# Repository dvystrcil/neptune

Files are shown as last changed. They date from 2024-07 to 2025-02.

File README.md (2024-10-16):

# Whats new?

I have moved all my pre OpenNept4une work into the archive folder. This includes all my notes for using the BTT Eddy on the Elegoo firmware.

I will be storing my current configs here soon, but keep in mind that they work with Open Nept4une and my not be advisable for stock Elegoo firware.

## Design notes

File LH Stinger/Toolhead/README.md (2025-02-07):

Start...

## What to expect
- @15g lighter
- Uses LH Stinger proven concepts
-- Compatible with Voron hotends (four bolt)
-- LDO Orbiter v2.x compatible
- Lose of 

## BOM
- LDO Oriter v2.x
- [TZ V6 2.0](https://www.aliexpress.us/item/3256808120176947.html)
- 5015 24v fans - Dual bearing, not hydrolic 
- 4010 24v fan
- [Elegoo Breakout Board](https://www.aliexpress.us/item/3256806050452317.html) (optional)

Print with PETG, ASA, or ABS 

Notes:
- The LDO and Elegoo breakout board wiring match one for one. The upper two are paired to one coil and the lower two are paired to the other coil.
- BTT Eddy loctions. Some loss of X on the screw-tilt, I may need to find a better location for the Eddy.

## What needs to be completed
- [ ] Input Shaping
- [ ] Filament Calibration
- [ ] Set new screw tilt locations
- [ ] Save everything
- [ ] Tidy up left side wire harness
- [ ] Reprint purge bucket with 9mm less height
- [ ] Investigate how to add a filament cutter
- [ ] Perhaps reprint in ASA
- [ ] Add some before and after info

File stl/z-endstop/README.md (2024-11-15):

STL files for makeing the z-endstop for use with the Elegoo Neptune 4/4 Pro (not Plus or Max)

License:
[CC BY-NC 4.0](https://creativecommons.org/licenses/by-nc/4.0/)

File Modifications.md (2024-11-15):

# My Modifications

A list of all the modifications I have done to my Neptune 4 Pro

| Type | Paid | Works? | Notes |
| :--- | ----: | :----: | :---- |
| [Silicone Bushings](https://www.amazon.com/gp/product/B09NNFQQ8T/ref=ppx_yo_dt_b_search_asin_title?ie=UTF8&psc=1) | $7.99 | Y | Springs were not holding position. |
| [Oldham Couplings (x2)](https://www.amazon.com/gp/product/B0BZ56F15T/ref=ppx_yo_dt_b_asin_title_o00_s00?ie=UTF8&th=1) | $8.99 | Y | Noticeable improvement in Z banding. |
| [Shroud](https://www.printables.com/model/812526-neptune-4-plus-max-3x-5015-fan-printhead-threaded) | $$ | Y | I could ditch the blower and have improved airflow on the nozzle (where the work happens). I will provide a price later) |
| [EMMC 32Gb](https://www.amazon.com/dp/B0D1K3TNQN?ref=ppx_yo2ov_dt_b_fed_asin_title) | $21.00 | Y | Used it for upgrading and storage space. |
| [Thrust Bearings](https://www.amazon.com/dp/B07QKKWM2R?ref=ppx_yo2ov_dt_b_fed_asin_title) | $7.54 | Y | I am using these to improve the life of my steppers |
| [KUSBA](https://www.amazon.com/gp/product/B0C734JL4Z/ref=ppx_yo_dt_b_search_asin_title?ie=UTF8&psc=1) | $15.69 | Y | Improved printing, less ghosting. |
| [BTT Eddy](https://biqu.equipment/products/bigtreetech-eddy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) | $24.98 | Y | Beautiful first layers. [Adapter](https://www.printables.com/model/928061-neptune-4-btt-eddy-adapter) |
| [Bimetal Nozzle](https://www.amazon.com/dp/B0CKYXZCYC?ref=ppx_yo2ov_dt_b_fed_asin_title) | $9.97 | M | Might be leaving some scaring. It does hold its heat well and I can print PETG-CF without issue. |
| [USB Hub](https://www.amazon.com/dp/B07L32B9C2?ref=ppx_yo2ov_dt_b_fed_asin_title&th=1) | $9.99 | Y | Needed for expansion. |
| [Elegoo Harden Steel Nozzel](https://www.amazon.com/dp/B0CY3T6FHC?ref=ppx_yo2ov_dt_b_fed_asin_title&th=1) | $9.99 | N | Doesn't hold the heat well. The Bimetal is performing better. |
| [Creality A/B Plate](https://www.amazon.com/dp/B0C4NDBY8Z) | $19.99 | Y | Love it. |
| [z endstop](https://github.com/dvystrcil/neptune/blob/main/Z%20End%20Stop%20Modification.md) | $$ | Y! | Absolutely love it. |
| Axis Locks | 
| Cable Chains |
| Filament Feeder |
| Camera |

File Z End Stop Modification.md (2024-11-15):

Notes on how I added a Z endstop to my Neptune 4 Pro. This should be compatible with the non-pro, however, due to the nonexistent off-bed range of the X axis on the Plus and Max a different solution will need to be designed.

## License
[CC BY-NC 4.0](https://creativecommons.org/licenses/by-nc/4.0/)

## Limitations
- If the nozzle is dirty, your offset is not going to be accurate
- It may be difficult to clean the nozzle without homing first
- you cannot use bed corners on the same side as the offset end stop

## Parts
- [Cable Endstop Mechanical Limit Optical Switch Connection Wire](https://www.amazon.com/gp/product/B0B6FHZLLF) Note: 1M is too long, if you can find even a third of that length it would work.
- [X/Y/Z Axis End Stop Limit Switch](https://www.amazon.com/gp/product/B098PXX6Q7)
- [2.6x16mm Dowel Pins](https://www.amazon.com/gp/product/B0BCFN4RHN0)
- [0406 Sleeve Bearings](https://www.amazon.com/gp/product/B0CXXGHT1P)
- 2 - M3*6 button head screws
- 1 - M4*20 hex head bolt with nut (poor man's t-nut)
- [Printable Parts](https://github.com/dvystrcil/neptune/tree/main/stl/z-endstop)

## Code
When reading this configs keep in mind that the Pro has a bed size of 235x235 so the center would be 117.5,117.5
```
[stepper_z]
...
endstop_pin: ^!PC3
homing_speed: 8
homing_retract_dist: 5
second_homing_speed: 3
```
```
[gcode_macro Z_ENDSTOP_CALIBRATE]
rename_existing: Z_ENDSTOP_CALIBRATE_RAW
gcode: 
  BED_MESH_CLEAR
  G28
  G90 # Abs positioning
  G1 X117.5 Y117.5 F6000  
  Z_ENDSTOP_CALIBRATE_RAW {rawparams}
```
```
[safe_z_home]
...
home_xy_position: -5,117.5
```
```
[bed_mesh]
...
zero_reference_position: 117.5,117.5
```

## Installation Pictures
The -Z pin PC3
PXL_20241104_004744595 MP
I had to remove the top and both of the bottom panels to route the wire through, but there is plenty of clearance.

There is a clearance issue that needs to be resolved. In my case, there is no pressure from the arm so the rubbing is minimal.


## On and Off the Plate
- 0.2 layer height
- Any filament is OK
- Brim Type: Mouse ear
- I used supports: Normal with Snug




## References
- https://www.youtube.com/watch?v=Q2uBK5XzX4I Note: this video fails to mention what the zero_reference_position does.
- https://www.klipper3d.org/G-Codes.html?h=z_offset_app#z_endstop_calibrate
- https://www.klipper3d.org/G-Codes.html?h=z_offset_app#z_offset_apply_endstop
- https://www.klipper3d.org/Endstop_Phase.html
- https://www.klipper3d.org/Bed_Mesh.html?h=zero_reference_position#configuring-the-zero-reference-position

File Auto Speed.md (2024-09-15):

# Testing Auto Speed 

## Where to find it:
https://github.com/Anonoei/klipper_auto_speed

## Some explanation on how to use it:
https://www.youtube.com/watch?v=8d49_QUmP9k

## Running AUTO_SPEED with Autotune set to `silent`

```
// AUTO SPEED found maximum acceleration after 114.36s
// | X max: 8089
// | Y max: 12601
// 
// Recommended values:
// | X max: 6471
// | Y max: 10081
```
```
// AUTO SPEED found maximum velocity after 134.67s
// | X max: 92
// | Y max: 352
// 
// Recommended values
// | X max: 74
// | Y max: 282
// Recommended velocity: 74
```
```
// AUTO SPEED found recommended acceleration and velocity after 249.04s
// | X max: a6471 v74
// | Y max: a10081 v282
// Recommended accel: 6471
// Recommended velocity: 74
```

AUTO_SPEED_GRAPH_2024-09-14_22_30_47_x

AUTO_SPEED_GRAPH_2024-09-14_22_34_53_y

## Running AUTO_SPEED with Autotune set to `performance`

```
// AUTO SPEED found maximum acceleration after 76.15s
// | X max: 97937
// | Y max: 97937
// 
// Recommended values:
// | X max: 78350
// | Y max: 78350
```
```
// AUTO SPEED found maximum velocity after 97.30s
// | X max: 1261
// | Y max: 965
// 
// Recommended values
// | X max: 1009
// | Y max: 772
// Recommended velocity: 772
```
```
// AUTO SPEED found recommended acceleration and velocity after 173.47s
// | X max: a78350 v1009
// | Y max: a78350 v772
// Recommended accel: 78350
// Recommended velocity: 772
```




## Running with Autotune set to `performance` and some different defaults

After talking with SilencedFrost he said the accel wasn't making sense. My numbers were the same as the video, which was odd. I did some poking around and found this issue https://github.com/Anonoei/klipper_auto_speed/issues/25

So I used the same numbers as the person in the issue:
```config
[auto_speed]
margin: 2.5 ; How far away from your axes to perform movements
accel_min: 1000.0 ; Minimum acceleration test may try
accel_max: 30000.0 ; Maximum acceleration test may try

velocity_min: 50.0 ; Minimum velocity test may try
velocity_max: 700.0 ; Maximum velocity test may try
```

```
// AUTO SPEED found maximum acceleration after 76.51s
// | X max: 29395
// | Y max: 29395
// 
// Recommended values:
// | X max: 23516
// | Y max: 23516
```
```
// AUTO SPEED found maximum velocity after 77.16s
// | X max: 686
// | Y max: 604
// 
// Recommended values
// | X max: 549
// | Y max: 483
// Recommended velocity: 483
```
```
// AUTO SPEED found recommended acceleration and velocity after 153.68s
// | X max: a23516 v549
// | Y max: a23516 v483
// Recommended accel: 23516
// Recommended velocity: 483
```

The numbers still sound a little suspicious. Shouldn't the velocity be hitting 700, since the uncapped run was at 772?

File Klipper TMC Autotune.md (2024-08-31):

# Klipper TMC Autotune Notes

Notes on my experimentation with getting the Klipper autotune working on my Elegoo Neptune 4 Pro

## Installation

Read and install: https://github.com/andrewmcgr/klipper_tmc_autotune

## Configuration

Based on what SilentedFrost has discovered these are some of the attributes of the steppers. I can confirm that I am using the BJ42D22-53V04 for the X, assuming the Y will be identical. I will have to find evidence for the others.



Specs on the steppers: https://www.3djake.com/elegoo/stepper-motor-4

```ini
########################################
# Klipper TMC Autotune configuration
########################################

[motor_constants bj42d22-53v04]             ; 1.2A version of the stepper motor
resistance: 2.1
inductance: 0.0046
holding_torque: 0.4
max_current: 1.20
steps_per_revolution: 200

[ autotune_tmc stepper_x]
motor: bj42d22-53v04
tuning_goal: auto

[ autotune_tmc stepper_y]
motor: bj42d22-53v04
tuning_goal: auto
```

## Fixing Packages

### Enum error
https://github.com/andrewmcgr/klipper_tmc_autotune/issues/40

run:
```bash
source ~/klippy-env/bin/activate
pip install enum
deactivate
```

### Signature error

run:
```bash
source ~/klippy-env/bin/activate
pip install funcsigs
deactivate
```

Change this line:
https://github.com/andrewmcgr/klipper_tmc_autotune/blob/main/| autotune_tmc.py#L3
```python
import math, logging, os
from enum import Enum
from inspect import signature
from . import tmc
```
to
```python
import math, logging, os
from enum import Enum
#from inspect import signature
from funcsigs import signature
from . import tmc
```
Probably a better way to do this so it can try the first and fall back on the second

## Performance

Since I only have the XY steppers tuning I will do an X offset print and compare times and the sound.

| Auto | Silent | Performance |
| :--- | :----- | :--- |
| 5m25s | 5m24s | 5m24s |
| autotune_tmc set stepper_x pwm_freq=2 | autotune_tmc set stepper_x pwm_freq=2 | autotune_tmc set stepper_x pwm_freq=2 |
| autotune_tmc stepper_x ncycles=219 pfdcycles=73 | autotune_tmc stepper_x ncycles=219 pfdcycles=73 | autotune_tmc stepper_x ncycles=219 pfdcycles=73 |
| autotune_tmc set stepper_x tbl=1 | autotune_tmc set stepper_x tbl=1 | autotune_tmc set stepper_x tbl=1 |
| autotune_tmc set stepper_x toff=1 | autotune_tmc set stepper_x toff=1 | autotune_tmc set stepper_x toff=1 | 
| autotune_tmc seting hysteresis based on 24.0 V | autotune_tmc seting hysteresis based on 24.0 V | autotune_tmc seting hysteresis based on 24.0 V |
| dcoilblank = 0.010435, dcoilsd = 0.003278 | dcoilblank = 0.010435, dcoilsd = 0.003278 | dcoilblank = 0.010435, dcoilsd = 0.003278 |
| hysteresis = 0, htotal = 0, hstrt = 1, hend = -1 | hysteresis = 0, htotal = 0, hstrt = 1, hend = -1 | hysteresis = 0, htotal = 0, hstrt = 1, hend = -1 |
| autotune_tmc set stepper_x hstrt=0 | autotune_tmc set stepper_x hstrt=0 | autotune_tmc set stepper_x hstrt=0 |
| autotune_tmc set stepper_x hend=2 | autotune_tmc set stepper_x hend=2 | autotune_tmc set stepper_x hend=2 |
| autotune_tmc set stepper_x sgthrs=40 | autotune_tmc set stepper_x sgthrs=40 | autotune_tmc set stepper_x sgthrs=40 |
| autotune_tmc using max PWM speed 176.661987 | autotune_tmc using max PWM speed 176.661987 | autotune_tmc using max PWM speed 176.661987 |
| autotune_tmc set stepper_x pwm_autoscale=True | autotune_tmc set stepper_x pwm_autoscale=True | autotune_tmc set stepper_x pwm_autoscale=True |
| autotune_tmc set stepper_x pwm_autograd=True | autotune_tmc set stepper_x pwm_autograd=True | autotune_tmc set stepper_x pwm_autograd=True |
| autotune_tmc set stepper_x pwm_grad=15 | autotune_tmc set stepper_x pwm_grad=15 | autotune_tmc set stepper_x pwm_grad=15 |
| autotune_tmc set stepper_x pwm_ofs=33 | autotune_tmc set stepper_x pwm_ofs=33 | autotune_tmc set stepper_x pwm_ofs=33 |
| autotune_tmc set stepper_x pwm_reg=15 | autotune_tmc set stepper_x pwm_reg=15 | autotune_tmc set stepper_x pwm_reg=15 |
| autotune_tmc set stepper_x pwm_lim=4 | autotune_tmc set stepper_x pwm_lim=4 | autotune_tmc set stepper_x pwm_lim=4 |
| autotune_tmc set stepper_x tpwmthrs=1048575 | autotune_tmc set stepper_x tpwmthrs=0 | autotune_tmc set stepper_x tpwmthrs=1048575 |
| autotune_tmc set stepper_x en_spreadcycle=True | autotune_tmc set stepper_x en_spreadcycle=False | autotune_tmc set stepper_x en_spreadcycle=True |
| autotune_tmc set stepper_x tcoolthrs=391(24.0) | autotune_tmc set stepper_x tcoolthrs=391(24.0) | autotune_tmc set stepper_x tcoolthrs=391(24.0) |
| autotune_tmc set stepper_x semin=2 | autotune_tmc set stepper_x semin=2 | autotune_tmc set stepper_x semin=2 |
| autotune_tmc set stepper_x semax=4 | autotune_tmc set stepper_x semax=4 | autotune_tmc set stepper_x semax=4 |
| autotune_tmc set stepper_x seup=3 | autotune_tmc set stepper_x seup=3 | autotune_tmc set stepper_x seup=3 |
| autotune_tmc set stepper_x sedn=2 | autotune_tmc set stepper_x sedn=2 | autotune_tmc set stepper_x sedn=2 |
| autotune_tmc set stepper_x seimin=1 | autotune_tmc set stepper_x seimin=1 | autotune_tmc set stepper_x seimin=1 |
| autotune_tmc set stepper_x iholddelay=12 | autotune_tmc set stepper_x iholddelay=12 | autotune_tmc set stepper_x iholddelay=12 |
| autotune_tmc set stepper_x multistep_filt=True | autotune_tmc set stepper_x multistep_filt=True | autotune_tmc set stepper_x multistep_filt=True |
| autotune_tmc set stepper_y pwm_freq=2 | autotune_tmc set stepper_y pwm_freq=2 | autotune_tmc set stepper_y pwm_freq=2 |
| autotune_tmc stepper_y ncycles=219 pfdcycles=73 | autotune_tmc stepper_y ncycles=219 pfdcycles=73 | autotune_tmc stepper_y ncycles=219 pfdcycles=73 |
| autotune_tmc set stepper_y tbl=1 | autotune_tmc set stepper_y tbl=1 | autotune_tmc set stepper_y tbl=1 |
| autotune_tmc set stepper_y toff=1 | autotune_tmc set stepper_y toff=1 | autotune_tmc set stepper_y toff=1 |
| autotune_tmc seting hysteresis based on 24.0 V | autotune_tmc seting hysteresis based on 24.0 V | autotune_tmc seting hysteresis based on 24.0 V |
! dcoilblank = 0.010435, dcoilsd = 0.004006 | dcoilblank = 0.010435, dcoilsd = 0.004006 | dcoilblank = 0.010435, dcoilsd = 0.004006 |
! hysteresis = -1, htotal = -1, hstrt = 1, hend = -2 | hysteresis = -1, htotal = -1, hstrt = 1, hend = -2 | hysteresis = -1, htotal = -1, hstrt = 1, hend = -2 |
| autotune_tmc set stepper_y hstrt=0 | autotune_tmc set stepper_y hstrt=0 | autotune_tmc set stepper_y hstrt=0 |
| autotune_tmc set stepper_y hend=1 | autotune_tmc set stepper_y hend=1 | autotune_tmc set stepper_y hend=1 |
| autotune_tmc set stepper_y sgthrs=40 | autotune_tmc set stepper_y sgthrs=40 | autotune_tmc set stepper_y sgthrs=40 |
| autotune_tmc using max PWM speed 171.091564 | autotune_tmc using max PWM speed 171.091564 | autotune_tmc using max PWM speed 171.091564 |
| autotune_tmc set stepper_y pwm_autoscale=True | autotune_tmc set stepper_y pwm_autoscale=True | autotune_tmc set stepper_y pwm_autoscale=True |
| autotune_tmc set stepper_y pwm_autograd=True | autotune_tmc set stepper_y pwm_autograd=True | autotune_tmc set stepper_y pwm_autograd=True |
| autotune_tmc set stepper_y pwm_grad=15 | autotune_tmc set stepper_y pwm_grad=15 | autotune_tmc set stepper_y pwm_grad=15 |
| autotune_tmc set stepper_y pwm_ofs=40 | autotune_tmc set stepper_y pwm_ofs=40 | autotune_tmc set stepper_y pwm_ofs=40 |
| autotune_tmc set stepper_y pwm_reg=15 | autotune_tmc set stepper_y pwm_reg=15 | autotune_tmc set stepper_y pwm_reg=15 |
| autotune_tmc set stepper_y pwm_lim=4 | autotune_tmc set stepper_y pwm_lim=4 | autotune_tmc set stepper_y pwm_lim=4 |
| autotune_tmc set stepper_y tpwmthrs=1048575 | autotune_tmc set stepper_y tpwmthrs=0 | autotune_tmc set stepper_y tpwmthrs=1048575 |
| autotune_tmc set stepper_y en_spreadcycle=True | autotune_tmc set stepper_y en_spreadcycle=False | autotune_tmc set stepper_y en_spreadcycle=True |
| autotune_tmc set stepper_y tcoolthrs=391(24.0) | autotune_tmc set stepper_y tcoolthrs=391(24.0) | autotune_tmc set stepper_y tcoolthrs=391(24.0) |
| autotune_tmc set stepper_y semin=2 | autotune_tmc set stepper_y semin=2 | autotune_tmc set stepper_y semin=2 |
| autotune_tmc set stepper_y semax=4 | autotune_tmc set stepper_y semax=4 | autotune_tmc set stepper_y semax=4 |
| autotune_tmc set stepper_y seup=3 | autotune_tmc set stepper_y seup=3 | autotune_tmc set stepper_y seup=3 |
| autotune_tmc set stepper_y sedn=2 | autotune_tmc set stepper_y sedn=2 | autotune_tmc set stepper_y sedn=2 |
| autotune_tmc set stepper_y seimin=1 | autotune_tmc set stepper_y seimin=1 | autotune_tmc set stepper_y seimin=1 |
| autotune_tmc set stepper_y iholddelay=12 | autotune_tmc set stepper_y iholddelay=12 | autotune_tmc set stepper_y iholddelay=12 |
| autotune_tmc set stepper_y multistep_filt=True | autotune_tmc set stepper_y multistep_filt=True | autotune_tmc set stepper_y multistep_filt=True |

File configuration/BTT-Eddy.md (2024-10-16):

# How to install BTT Eddy for the Elegoo Neptune 4 Series 3D Printer

## Notes for now

### Requirements

- Own the BTT Eddy
- Update your printer with the krakjoe's Klipper and Moonraker. This is all in the README.md
- Watch the [BTT Eddy installation guide](https://drive.google.com/file/d/1uXiymZxoWhvRIwTwojOh0fGKmjitoytf/view)
- Read the [BTT Eddy instllation docs](https://github.com/bigtreetech/Eddy/blob/master/README.md)

Note: Ignore the steps to use Kiauh from the BTT instructions! You did these steps following krakjoe's Klipper and Moonraker method.

# Step 1 - Install the Eddy

There are a couple ways to do this and there are several YouTubes out there that cover it. 

I used the BTT-Eddy_Adapter_v05.stl mounting bracket for my printer:
https://www.printables.com/model/928061-neptune-4-btt-eddy-adapter

# Step 2 - Compiling the firmware

I will refer back to the BTT documenatin for this: [Compiling Firmware](https://github.com/bigtreetech/Eddy?tab=readme-ov-file#compiling-firmware)

# Step 3 - Updating your printer.cfg

Add these marcos to your printer.cfg.
- Remove the old `[probe]` section
- You will need to modify the `[bed_mesh]` section to account for the new position of the probe. Remember the Eddy is chucky. The original stock probe is not. The settings bellow I found are good for my Neptune 4 Pro AND the mount I chose to use.  

```ini
#####################################################################
# 	Probe
#####################################################################

[mcu eddy]
serial: /dev/serial/by-id/usb-Klipper_rp2040_45474E621B0483CA-if00

[temperature_sensor btt_eddy_mcu]
sensor_type: temperature_mcu
sensor_mcu: eddy
min_temp: 10
max_temp: 100

[probe_eddy_current btt_eddy]
sensor_type: ldc1612
z_offset: 1.0
#i2c_address:
i2c_mcu: eddy
i2c_bus: i2c0f
# x_offset: -24.25
# y_offset: 20.45
# new Probe values:
#Eddy 0Deg x=-36.16 y=31.66
x_offset: -36.16
y_offset: 31.66
data_rate: 500

[temperature_probe btt_eddy]
sensor_type: Generic 3950
sensor_pin: eddy:gpio26
horizontal_move_z: 2

[bed_mesh]
horizontal_move_z: 1
speed: 400
mesh_min: 15, 31.66 # for N4 Pro
mesh_max: 198.84, 220.00
probe_count: 21, 21 # keeping it an odd number will give you a midpoint.
algorithm: bicubic

[safe_z_home]
home_xy_position: 141,98 
speed: 200
z_hop: 10                 
z_hop_speed: 25
```

# Step 4 - Configuring your Eddy

This step is all on on Big Tree Tech's side. [Follow their documents](https://github.com/bigtreetech/Eddy/blob/master/README.md)

# Notes

## Using z_offset for Your Filament

While it is great that the Eddy always works from a 0 Z offset it doesn't allow for adjusting the "squish" you want when you lay down that first layer. There are several ways to do this. BTT has their own macros, In Ocra Slicer you can add the Z offset the start G-Code... but how do you get there? Here is what I like to use, others have their own methods... and it can be debated ad nauseam.

I start by running a first layer test, and stepping the tool head up or down as needed. I have the option of using either the Elegoo UI with 0.01 steps or Fluidd with 0.005 steps. When you get that perfect "squish" then finish the print and run these commands
```
Z_OFFSET_APPLY_PROBE
SAVE_CONFIG
```
Klipper will restart and your z_offset will be 0 again.

- Do you need to repeat steps continuously? No. Not unless you lost the mapping completely. You only really need to redo your first layer test when you change the filament or your bed moves a bit.
- Do you need to run the tilt screw marco? Only if you think your bed needs to be retramed. Then redo your first layer test, you may have to do the paper trick first if it was off-level a lot.
- Do I need to save the Z_OFFSET? You should, but if you don't when you shut down your printer or restart Klipper it will reset to 0 and lose the baby steps you worked hard to find.

## Adaptive Meshing

Back in January 2024 Klipper brought in the excellent use of KAMP. To use adaptive meshing with Eddy you only need to update your `[PRINT_START]` gcode.
Example Only: Your PRINT_START may be different.
```ini
[gcode_macro PRINT_START]         
gcode:
    SAVE_VARIABLE VARIABLE=was_interrupted VALUE=True
	  G92 E0                                         
    BED_MESH_CLEAR                                     
	  G90             
    BED_MESH_CALIBRATE ADAPTIVE=1 METHOD=scan SCAN_MODE=rapid algorithm=bicubic #PROFILE=6          
    CLEAR_PAUSE
    M117 Printing
```
Note: Elegoo is specifically looking at PROFILE 6 when showing it on the UI. Since we want adaptive meshing `ADAPTIVE=1` we will not load `PROFILE=6`. 


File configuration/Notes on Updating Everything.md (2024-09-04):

# Updating Klipper, Moonraker, Fluidd and Kiauh

The goal is to bring the N4 series up to date. There are still some outstanding tasks, but it's looking very promising.

Why I chose Kiauh instead of a completely scripted solution is to keep the sources of truth for all these tools. I don't want to document how to install all these parts whole cloth, and maintaining them would be painful. If there are differences, and I expect there will be since many of us have bricked in the past, what are they? If we can understand how Elegoo did things we can repeat them, and perhaps improve on them.

The bottom line, let the contributors of Klipper, Moonraker, Fluidd, and Kiauh do their thing. Our focus is to alter just the bits the printer needs to function.



Note: Consider the work here at a BETA stage. Use at your own risk. Restoring can be as simple as coping a folder back.

## Tasks:
- [x] Update python to 3.12.5
- [x] Use the alpha Kiauh
- [x] Update Fluidd
- [x] Update Moonraker
- [x] Update Klipper
- [ ] See what breaks, document it, and create patches?
- [ ] What is so Elegoo about the their Klipper?
- [ ] What happens when you do a firmware update? There are files for Klipper and Moonraker in the extras.
- [ ] Education. It's OK if you have untracked files reported in Fluidd. You might have installed something like autotune or califlower

Side Note: This effort does not supersede the excellent work being done over on the [OpenNept4une](https://github.com/OpenNeptune3D/OpenNept4une). At some point, the N4 series will be EOL by Elegoo and OpenNept4une will be the path forward.

## Step 1: Install the mandatory tools
https://github.com/dvystrcil/neptune/blob/main/Update%20Utilities.md

## Step 2: Update Kiauh
```bash
cd ~/kiauh
pyenv local 3.10.14 # using the local option will pin it for that folder.
./kiauh.sh
```
If it asks you about the new alpha v6 it's safe to try it out. I used it exclusively through this whole exercise.

## Step 3: Update Fluidd
Do this from Kiauh. No need to wait.

## Step 4: Update Moonraker
Note: If you have followed my previous guild that installs Krakjoe's repos, you must delete the `.git` folder.
```bash
cd ~/moonraker
# sudo rm -rf .git # see note
git init
git remote add origin https://github.com/Arksine/moonraker.git
git fetch origin master
git reset --hard FETCH_HEAD
git pull origin master
./scripts/data-path-fix.sh
```

## Step 5: Update Klipper

### Part A: Back up your folders
```bash
cd ~
sudo mv klipper klipper.bak
sudo mv klipper-env klipper-env.bak
```

### Part B: Update the python venv
```bash
pyenv global 3.10.14
pip3 install --upgrade pip
pip3 install --upgrade virtualenv
virtualenv -p python3 klippy-env
```

### Part C: Get the latest Klipper
```bash
cd ~/klipper
# sudo rm -rf .git # see note
git init
git remote add origin https://github.com/Klipper3d/klipper.git
git fetch origin master
git reset --hard FETCH_HEAD
git pull origin master
```

### Part D: Restore any Elegoo specific files
Note: It is still not known if there are more files than these, or even if we need all of them.
```bash
cd ~/klipper.bak
cp -R -u -p . ~/klipper
```

Restart your klipper
```bash
sudo systemctl restart klipper
```
Other commands are:
- systemctl status klipper
- sudo systemctl stop klipper
- sudo systemctl start klipper

## Post Installation
- [The Macro max_accel_to_decel Has Been Depricated](https://github.com/dvystrcil/neptune?tab=readme-ov-file#the-macro-max_accel_to_decel-has-been-depricated)
- [Elegoo's Configuration](https://github.com/dvystrcil/neptune/blob/main/README.md#elegoos-configuration)

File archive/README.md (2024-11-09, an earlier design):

# As of Sept 29th, 2024
I have switched to OpenNept4une. I will archive a lot of the work I have done here so it's not lost, but it is no longer representative of my printer configuration.

# There may be another way...
https://github.com/dvystrcil/neptune/blob/main/Notes%20on%20Updating%20Everything.md

# How to Update Neptune 4 Using krakjoe's Method

Laying down some expectations... I put this repo together to accomplish a few goals
- A place to back up my configuration
- A place to update my Neptune 4 Pro using automation
- A place to practice using Ansible

I am leaning heavily on the work done by krakjoe, a user out on the Elegoo Discord. He was able to provide and update Klipper and Moonraker specifically for use with the BTT Eddy probe. This resulted in allowing us to bring our Neptunes up to spec with the rest of the world. Let's be clear. He is allowed to do this. He is doing this on his own time. He is not affiliated with Elegoo.

If you came here looking for a more open and up-to-date way to keep your Neptune up to spec, there is the [OpenNept4une project](https://github.com/OpenNeptune3D/OpenNept4une), where you can get the latest Klipper, Moonraker, etc... They are a fine team and as an open source project I encourage any who can help to please do so.

Finally, I am not an expert in 3D printers, Klipper, or Moonraker... this is a hobby I enjoy dabbling in. 

If you ask me for support, please read that last sentence again. I can only help with things that I have personally written in this repo.

What to expect from this repo:
- A guide to installing krakjoe's work. I hope you can leverage the ansible playbooks I have written.
- A view into my personal printer configs. Nothing special here folks, your printer config will likely be different. Move along...

## Installation

### Requirements

You need to do a few things before you begin
- Install Ansible
- Fork or pull this repo to where you are doing the work. Cloning to your printer is OK if you have the space available.
- Update your printer to the latest firmware. If you know what you are doing you could probably use older firmware, but I started by updating to `NEPTUNE 4 PRO - APP_V1.1.3.1-UI_1.2.14-20240705-EN` which is for my printer (Neptune 4 Pro).

### Step 0 - The Automated Way of 1 thru 3

Clone this repo
```bash
git clone https://github.com/dvystrcil/neptune.git
cd neptune
```

Change directory to the `ansible` folder, make `run-update.sh` executable and run it
```bash
cd ansible
sudo chmod +x run-update.sh
./run-update.sh
```

Let Ansible do its thing. It should take about 5 minutes. If a reboot occurs then a kernel update is applied (rare occurrence). Just run-update.sh again.

#### Extra Credit: Correct your Time Zone
Edit the `playbooks/system/time-zone.yaml` so the `name: America/Los_Angeles` reflects the zone you want. Then come back to the ansible directory and run:

```bash
ansible-playbook -i inventory.ini playbooks/system/time-zone.yaml
```

More Extra Credit: You may have caught on that the playbooks are fairly granular. This means you can pick what task you want, even mix them around, or edit them to your liking. There are tons of resources about ansible out there and to be honest their documenation is pretty good.

### Step 1 - Update Your OS

So you seem to be someone who likes to type a lot. Fair enough.

Update your sources, because if they are original, it's broken.

Open your `/etc/apt/sources.list` in your favorite editor (like nano), and replace this line:

```bash
deb http://deb.debian.org/debian buster-backports main contrib non-free
```
with this:
```bash
deb http://archive.debian.org/debian buster-backports main contrib non-free
```

Then, update your OS
```bash
sudo apt update && sudo apt upgrade -y && sudo apt autoremove -y
```

### Step 2 - Update Klipper

Here is where you get to see how we are leaning into krakjoe's work. 

```bash
cd /home/mks/klipper
git init
git remote add n4.klipper https://git.krakjoe.dev/n4.klipper.git
git fetch n4.klipper n4/master
git reset --hard FETCH_HEAD
git pull n4.klipper n4/master
```
Why are we initializing a git repo? It's because Elegoo have their own repo and does not want others to pull from it. So they delete their `.git` folder.

#### The Macro `max_accel_to_decel` Has Been Depricated 

You can read more details about this on the [Klipper Config Changes](https://www.klipper3d.org/Config_Changes.html) log. 

If you are seeing this message in Klipper you need to edit your printer.cfg with the following:



`[gcode_macro PRINT_END]`
Replace:
```ini
    {% set RUN_DECEL    = printer.configfile.settings['printer'].max_accel_to_decel|float %}
    SET_VELOCITY_LIMIT VELOCITY={RUN_VELOCITY} ACCEL={RUN_ACCEL} ACCEL_TO_DECEL={RUN_DECEL}
```
with:
```ini
    {% set RUN_CRUISE   = printer.configfile.settings['printer'].minimum_cruise_ratio|float %}
    SET_VELOCITY_LIMIT VELOCITY={RUN_VELOCITY} ACCEL={RUN_ACCEL} MINIMUM_CRUISE_RATIO={RUN_CRUISE}
```

`[gcode_macro CANCEL_PRINT]`
Replace:
```ini
    {% set RUN_DECEL    = printer.configfile.settings['printer'].max_accel_to_decel|float %}
    SET_VELOCITY_LIMIT VELOCITY={RUN_VELOCITY} ACCEL={RUN_ACCEL} ACCEL_TO_DECEL={RUN_DECEL}
```
with:
```ini
    {% set RUN_CRUISE   = printer.configfile.settings['printer'].minimum_cruise_ratio|float %}
    SET_VELOCITY_LIMIT VELOCITY={RUN_VELOCITY} ACCEL={RUN_ACCEL} MINIMUM_CRUISE_RATIO={RUN_CRUISE}
```

`[printer]`
Remove the `max_accel_to_decel` property:
```ini
max_accel_to_decel: 20000 
```

If you are not using the `[adxl345]` or `[resonance_tester]` (only the plus and max have this built in) and you have not added an accellarometer yourself. Then remove these sections from your printer.cfg.

#### Elegoo's Configuration
Before you run leveling you must edit elegoo_conf.ini `/home/mks/Desktop/myfile/znp/znp_tjc_klipper/elegoo_conf.ini`

Under `[printer_offset]`
```ini
z_offset                       = 0.00
```
Under `[level_mode]`
```ini
level_points                   = 6
```
This will ensure your G29 (from snippets) macro works; it will cause the Elegoo firmware to load the profile named 6 whenever it loads a profile.

This profile should represent the entire bed, do not use this name for adaptive meshing.

### Step 3 - Update Moonraker

```bash
cd /home/mks/moonraker
git init
git remote add n4.moonraker https://git.krakjoe.dev/n4.moonraker.git
git fetch n4.moonraker n4/master
git reset --hard FETCH_HEAD
git pull n4.moonraker n4/master
./scripts/data-path-fix.sh
```

A note about `data-path-fix.sh`: This is a script that corrects all the open source Klipper and Moonraker pathing to Elegoo's requirements. If you update either Klipper or Mookraker using krakjoe work, its important to run this again.

### Step 4 - Update Kiauh and Fluidd

Here is where I stopped trying to automate things. As it is Kiauh is already a nice tool why not use it?

```bash
cd /home/mks/kiauh
```
If it asks to update Kiauh, say yes. Run it again if needed. When you get to the menu you want to choose Update, and then Fluidd. If you update Klipper or Mookraker, you are getting the non-elegoo versions. It will overwrite all the work you have just done in steps 2 and 3.



The git errors are expected. This is the side effect of pulling Klipper and Moonraker down from another remote source.



### Step 5 - Update Your Printer Configurations

TBD - lots of compare edit work

I automated some parts

- moonraker.config

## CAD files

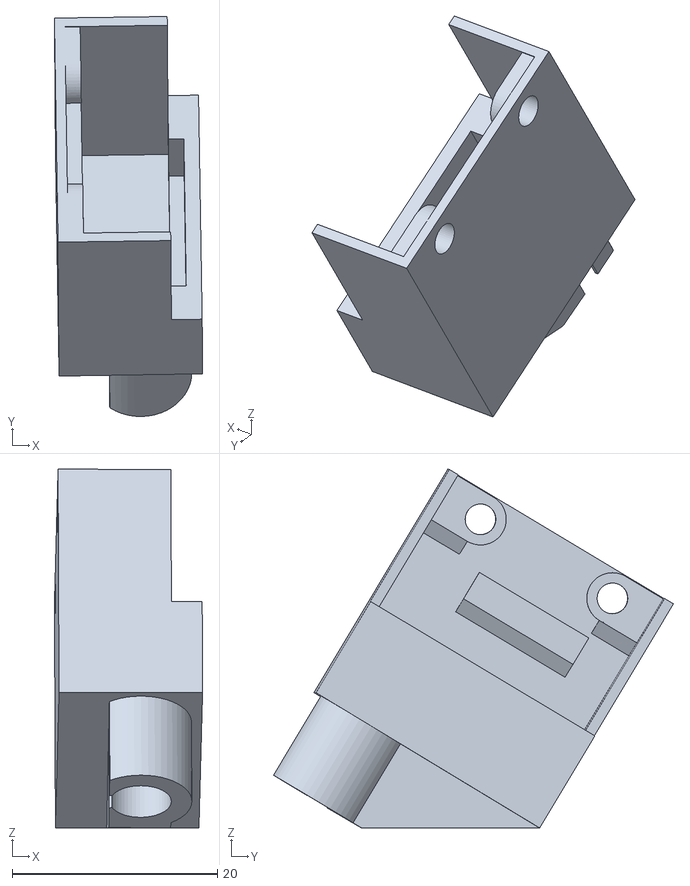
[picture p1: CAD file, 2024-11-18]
stl/z-endstop/z-offset endstop-cover.stl
14.4 x 39.0 x 35.0

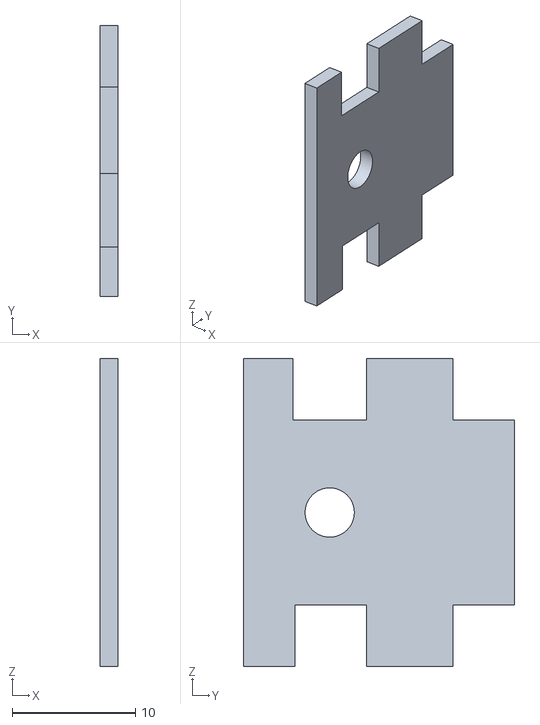
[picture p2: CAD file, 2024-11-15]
stl/z-endstop/z-offset endstop-baseplate.stl
1.50 x 22.0 x 25.0

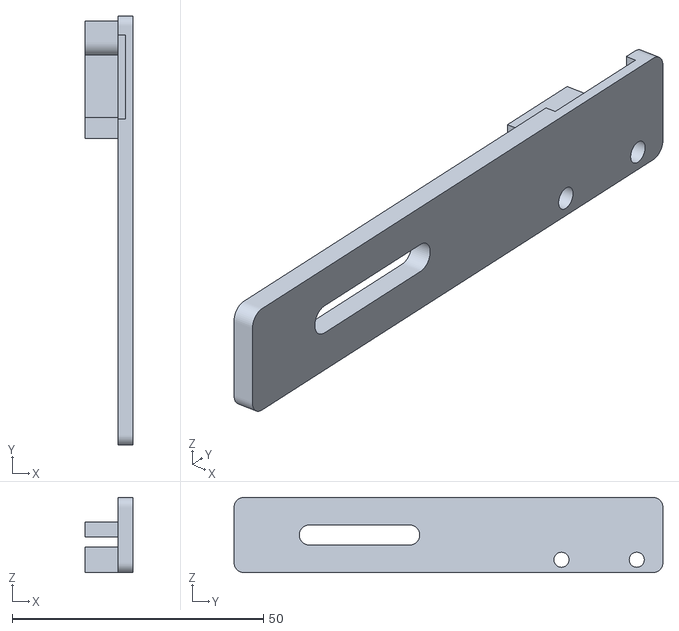
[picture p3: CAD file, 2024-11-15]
stl/z-endstop/z-offset endstop-arm.stl
9.50 x 85.5 x 15.0

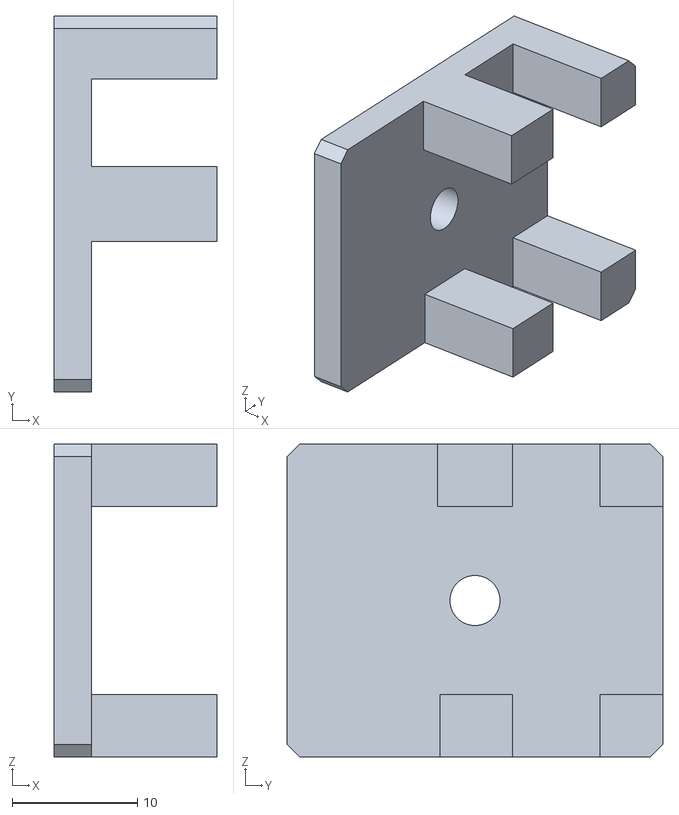
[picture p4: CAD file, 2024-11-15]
stl/z-endstop/z-offset endstop-base with keepers.stl
13.0 x 30.0 x 25.0

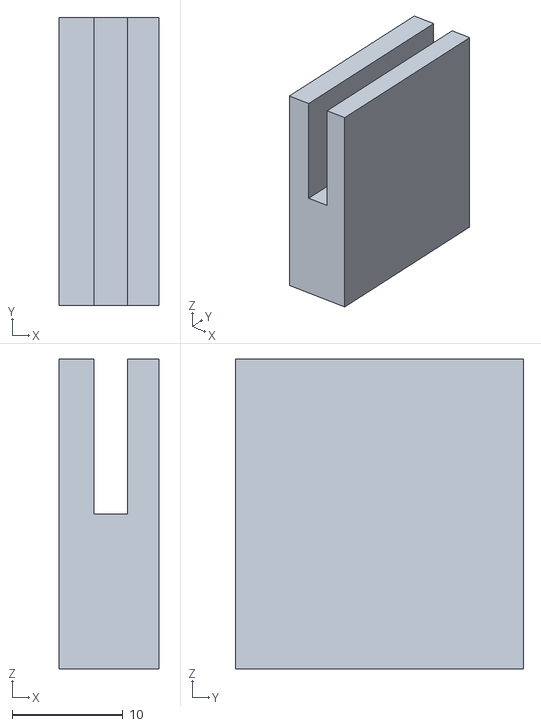
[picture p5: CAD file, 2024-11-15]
stl/z-endstop/z-offset endstop-arm spacer.stl
9.00 x 26.0 x 28.0

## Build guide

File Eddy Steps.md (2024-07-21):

Don't read too much into this. I was gathering info.

- Update to the latest elegoo firmware
- Replace Macros, (see snippets)
- Comment/Remove `max_accel_to_decel` in `printer` section of `printer.cfg`
- Replace `Probe` section in config, as above
- Replace `moonraker.conf` (see snippets) >> probably means to remove the deprecated sections
- Update klipper to master >> This is probably not correct for everyone. Build the firmware normal.
  - `cd ~/klipper`
  - make menuconf
  - Follow the recommendations for the mcu
  - plugin the BTT Eddy while holding the boot button
  - run `lsusb` to make sure the Eddy has an address
  - `make clean`
  - `make flash FLASH_DEVICE=2e8a:0003`
  - find device `ls /dev/serial/by-id/*`
  - Take note of the name, it's not the same for some. You will use this in the printer.cfg
- Update klipper with eddy and n4 support
  - `git remote add n4.klipper https://git.krakjoe.dev/n4.klipper.git`
  - `git fetch n4.klipper`
  - `git checkout n4/eddy`
- Update moonraker to master with n4 support
  - `cd ~/moonraker`
  - `git remote add n4.moonraker https://git.krakjoe.dev/n4.moonraker.git`
  - `git fetch n4.moonraker`
  - `git reset --hard`
  - `git checkout n4/master`
  - Replace `deb http://deb.debian.org/debian buster-backports main contrib non-free` in `/etc/apt/sources.list` with `deb http://archive.debian.org/debian buster-backports main contrib non-free`
  - `./scripts/data-path-fix.sh`
- Update fluidd
  - Use `kiauh` (`kiauh` itself requires and will prompt for an update first, this is safe)
- Restart system services
  - `systemctl restart klipper`
  - `systemctl restart moonraker`

Before you run levelling using procedure documented in eddy repo, you must edit elegoo_conf.ini (here? ./Desktop/myfile/znp/znp_tjc_klipper/elegoo_conf.ini):

Under `[printer_offset]`
```
z_offset                       = 0.00
```
Under `[level_mode]`
```
level_points                   = 6
```

Will ensure your G29 (from snippets) macro works; it will cause the elegoo firmware to load the profile named 6 whenever it loads a profile.

This profile should represent the entire bed, do not use this name for adaptive meshing.

The screen must not be used for probe calibration or meshing, the procedure outlined by BTT must now be followed

Here is my probe section, all changes required by eddy are contained in this section, this should replace the section with the same header in configuration:

### Probe section

 ```ini
#####################################################################
#     Probe
#####################################################################

[mcu eddy]
serial: /dev/serial/by-id/usb-Klipper_rp2040_eddy-if00

[temperature_sensor btt_eddy_mcu]
sensor_type: temperature_mcu
sensor_mcu: eddy
min_temp: 10
max_temp: 100

[probe_eddy_current btt_eddy]
sensor_type: ldc1612
z_offset: 1.0
#i2c_address:
i2c_mcu: eddy
i2c_bus: i2c0f
# x_offset: -24.25
# y_offset: 20.45
# new Probe values:
#Eddy 0Deg x=-36.16 y=31.66
x_offset: -36.16
y_offset: 31.66
data_rate: 500

[temperature_probe btt_eddy]
sensor_type: Generic 3950
sensor_pin: eddy:gpio26
horizontal_move_z: 2

[bed_mesh]
horizontal_move_z: 1
speed: 400
mesh_min: 21,21
mesh_max: 300.75,300.75
probe_count: 25, 25
algorithm: bicubic

[safe_z_home]
home_xy_position: 189.25,144.55 
speed: 200
z_hop: 10                 
z_hop_speed: 25

[screws_tilt_adjust]
screw1_name: front left screw
screw1: 55,10
screw2_name: rear left screw
screw2: 55,180
screw3_name: rear right screw
screw3: 225,180
screw4_name: front right screw
screw4: 225,10
horizontal_move_z: 10
speed: 200
screw_thread: CW-M4  # Use CW for Clockwise and CCW for Counter Clockwise

#[probe]
#pin:^PA11
#x_offset: -24.25
#y_offset: 20.45
#z_offset: 0.0
#speed: 10.0
#samples: 2
#samples_result: median
#sample_retract_dist: 3.0
#samples_tolerance: 0.05
#samples_tolerance_retries: 5

#[bed_mesh]
#speed:500                
#horizontal_move_z:10     
#mesh_min:15,21           
#mesh_max:210,211        
#probe_count:6,6          
#algorithm:bicubic
#bicubic_tension:0.2
#mesh_pps: 2, 2   
#fade_start:5.0
#fade_end:30.0  
```
This is correct for plus, using the other configurations as a base, you can copy or derive the correct values for mesh_min/max etc ...
Once you have switched branches, the "virtual mcu" (which is a linux process), must be recompiled using the normal make flash workflow, you may either go through menuconfig and configure the linux process build (and document how to do this), or you may use the virtualmcu.config from the ON project (and document how to do that) ...

So far, elegoo have included klipper and moonraker in their update packages, so installing elegoo provided updates over this mod will wipe out the support.
If they don't, and continue to make changes to klipper and moonraker, users will have to apply the update and set (or reset) branches to branches with those changes ported ... (edited)
afaict I'm licensed to repackage the updates contained in ELEGOO_UPDATE_DIR (just not screen firmware blobs), that's also an option ...

<!-- git init
git remote add n4.moonraker https://git.krakjoe.dev/n4.moonraker.git
git fetch n4.moonraker n4/master
git reset --hard FETCH_HEAD
git pull n4.moonraker n4/master -->

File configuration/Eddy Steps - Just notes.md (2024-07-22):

Don't read too much into this. I was gathering info.

- Update to the latest elegoo firmware
- Replace Macros, (see snippets)
- Comment/Remove `max_accel_to_decel` in `printer` section of `printer.cfg`
- Replace `Probe` section in config, as above
- Replace `moonraker.conf` (see snippets) >> probably means to remove the deprecated sections
- Update klipper to master >> This is probably not correct for everyone. Build the firmware normal.
  - `cd ~/klipper`
  - make menuconf
  - Follow the recommendations for the mcu
  - plugin the BTT Eddy while holding the boot button
  - run `lsusb` to make sure the Eddy has an address
  - `make clean`
  - `make flash FLASH_DEVICE=2e8a:0003`
  - find device `ls /dev/serial/by-id/*`
  - Take note of the name, it's not the same for some. You will use this in the printer.cfg
- Update klipper with eddy and n4 support
  - `git remote add n4.klipper https://git.krakjoe.dev/n4.klipper.git`
  - `git fetch n4.klipper`
  - `git checkout n4/eddy`
- Update moonraker to master with n4 support
  - `cd ~/moonraker`
  - `git remote add n4.moonraker https://git.krakjoe.dev/n4.moonraker.git`
  - `git fetch n4.moonraker`
  - `git reset --hard`
  - `git checkout n4/master`
  - Replace `deb http://deb.debian.org/debian buster-backports main contrib non-free` in `/etc/apt/sources.list` with `deb http://archive.debian.org/debian buster-backports main contrib non-free`
  - `./scripts/data-path-fix.sh`
- Update fluidd
  - Use `kiauh` (`kiauh` itself requires and will prompt for an update first, this is safe)
- Restart system services
  - `systemctl restart klipper`
  - `systemctl restart moonraker`

Before you run levelling using procedure documented in eddy repo, you must edit elegoo_conf.ini (here? ./Desktop/myfile/znp/znp_tjc_klipper/elegoo_conf.ini):

Under `[printer_offset]`
```
z_offset                       = 0.00
```
Under `[level_mode]`
```
level_points                   = 6
```

Will ensure your G29 (from snippets) macro works; it will cause the elegoo firmware to load the profile named 6 whenever it loads a profile.

This profile should represent the entire bed, do not use this name for adaptive meshing.

The screen must not be used for probe calibration or meshing, the procedure outlined by BTT must now be followed

Here is my probe section, all changes required by eddy are contained in this section, this should replace the section with the same header in configuration:

### Probe section

 ```ini
#####################################################################
#     Probe
#####################################################################

[mcu eddy]
serial: /dev/serial/by-id/usb-Klipper_rp2040_eddy-if00

[temperature_sensor btt_eddy_mcu]
sensor_type: temperature_mcu
sensor_mcu: eddy
min_temp: 10
max_temp: 100

[probe_eddy_current btt_eddy]
sensor_type: ldc1612
z_offset: 1.0
#i2c_address:
i2c_mcu: eddy
i2c_bus: i2c0f
# x_offset: -24.25
# y_offset: 20.45
# new Probe values:
#Eddy 0Deg x=-36.16 y=31.66
x_offset: -36.16
y_offset: 31.66
data_rate: 500

[temperature_probe btt_eddy]
sensor_type: Generic 3950
sensor_pin: eddy:gpio26
horizontal_move_z: 2

[bed_mesh]
horizontal_move_z: 1
speed: 400
mesh_min: 21,21
mesh_max: 300.75,300.75
probe_count: 25, 25
algorithm: bicubic

[safe_z_home]
home_xy_position: 189.25,144.55 
speed: 200
z_hop: 10                 
z_hop_speed: 25

[screws_tilt_adjust]
screw1_name: front left screw
screw1: 55,10
screw2_name: rear left screw
screw2: 55,180
screw3_name: rear right screw
screw3: 225,180
screw4_name: front right screw
screw4: 225,10
horizontal_move_z: 10
speed: 200
screw_thread: CW-M4  # Use CW for Clockwise and CCW for Counter Clockwise

#[probe]
#pin:^PA11
#x_offset: -24.25
#y_offset: 20.45
#z_offset: 0.0
#speed: 10.0
#samples: 2
#samples_result: median
#sample_retract_dist: 3.0
#samples_tolerance: 0.05
#samples_tolerance_retries: 5

#[bed_mesh]
#speed:500                
#horizontal_move_z:10     
#mesh_min:15,21           
#mesh_max:210,211        
#probe_count:6,6          
#algorithm:bicubic
#bicubic_tension:0.2
#mesh_pps: 2, 2   
#fade_start:5.0
#fade_end:30.0  
```
This is correct for plus, using the other configurations as a base, you can copy or derive the correct values for mesh_min/max etc ...
Once you have switched branches, the "virtual mcu" (which is a linux process), must be recompiled using the normal make flash workflow, you may either go through menuconfig and configure the linux process build (and document how to do this), or you may use the virtualmcu.config from the ON project (and document how to do that) ...

So far, elegoo have included klipper and moonraker in their update packages, so installing elegoo provided updates over this mod will wipe out the support.
If they don't, and continue to make changes to klipper and moonraker, users will have to apply the update and set (or reset) branches to branches with those changes ported ... (edited)
afaict I'm licensed to repackage the updates contained in ELEGOO_UPDATE_DIR (just not screen firmware blobs), that's also an option ...

```ini
[gcode_macro G29]
gcode:
      M400
      BED_MESH_CLEAR
      G28
      BED_MESH_CALIBRATE PROFILE=6 METHOD=scan SCAN_MODE=rapid algorithm=bicubic
      M400
      G4 P2000
      G91 
      G1 Z5 F300 
      G90
      G28 Z
      G1 X215 Y215 F12000
      G1 Z0 F300
```

```ini
[gcode_macro PRINT_END]
gcode:
    SAVE_VARIABLE VARIABLE=was_interrupted VALUE=False
    RUN_SHELL_COMMAND CMD=clear_plr
    clear_last_file
    {% set RUN_VELOCITY = printer.configfile.settings['printer'].max_velocity|float %}
    {% set RUN_ACCEL    = printer.configfile.settings['printer'].max_accel|float %}
    {% set RUN_CRUISE   = printer.configfile.settings['printer'].minimum_cruise_ratio|float %}
    SET_VELOCITY_LIMIT VELOCITY={RUN_VELOCITY} ACCEL={RUN_ACCEL} MINIMUM_CRUISE_RATIO={RUN_CRUISE}

    M220 S100
    M221 S100
    {% set z = params.Z|default(100)|int %}
    {% if (printer.gcode_move.position.z+5) < z %}   ##如果当前gcode-Z位置小于最大极限位置
      G90                                         ; absolute positioning
      G1 Z{z+5} F6000                       ; park nozzle at rear
    {% endif %}
    TURN_OFF_HEATERS
    M107
    M84 X Y E
```

```ini
[gcode_macro CANCEL_PRINT]
rename_existing: BASE_CANCEL_PRINT
gcode:
      SAVE_VARIABLE VARIABLE=was_interrupted VALUE=False
      RUN_SHELL_COMMAND CMD=clear_plr
      clear_last_file
      {% set RUN_VELOCITY = printer.configfile.settings['printer'].max_velocity|float %}
      {% set RUN_ACCEL    = printer.configfile.settings['printer'].max_accel|float %}
      {% set RUN_CRUISE   = printer.configfile.settings['printer'].minimum_cruise_ratio|float %}
      SET_VELOCITY_LIMIT VELOCITY={RUN_VELOCITY} ACCEL={RUN_ACCEL} MINIMUM_CRUISE_RATIO={RUN_CRUISE}
      {% set z = params.Z|default(100)|int %}  
      {% set x_park = params.X|default(printer.toolhead.axis_minimum.x+5)|int %} 
      {% set y_park = params.Y|default(printer.toolhead.axis_maximum.y-5)|int %} 
      SET_IDLE_TIMEOUT TIMEOUT={printer.configfile.settings.idle_timeout.timeout} 
      SDCARD_RESET_FILE
      M220 S100
      M221 S100
      M400             ; wait for buffer to clear
      G91             ; relative positioning
      M83           ; zero the extruder
      G1 E-10.0 F1200       ; retract filament
      TURN_OFF_HEATERS
      M107             ; turn off fan
    {% if (printer.gcode_move.position.z+5) < z %}
      G90             ; absolute positioning
      G0 X{x_park} Y{y_park} Z{z+5} F6000       ; park nozzle at rear
    {% endif %}
    {%if (printer.gcode_move.position.z+5) >= z %}
    {%if (printer.gcode_move.position.z+5) < printer.toolhead.axis_maximum.z %}
      G91             ; relative positioning
      G1 Z5 F300
      G90
      G0 X{x_park} Y{y_park} F6000       ; park nozzle at rear
      {% else %}
      G90
      G0 X{x_park} Y{y_park} Z{printer.toolhead.axis_maximum.z} F6000       ; park nozzle at rear
    {% endif %}
    {% endif %}
      M84 X Y E
```

moonraker.conf:

```ini
[server]
host: 0.0.0.0
port: 7125
klippy_uds_address: /tmp/klippy_uds

[authorization]
trusted_clients:
    10.0.0.0/8
    127.0.0.0/8
    169.254.0.0/16
    172.16.0.0/12
    192.168.0.0/16
    FE80::/10
    ::1/128
cors_domains:
...
```

<!-- git init
git remote add n4.moonraker https://git.krakjoe.dev/n4.moonraker.git
git fetch n4.moonraker n4/master
git reset --hard FETCH_HEAD
git pull n4.moonraker n4/master -->

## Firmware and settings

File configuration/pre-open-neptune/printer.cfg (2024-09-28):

####################################################################################
# Machine type: NEPTUNE 4 PRO
# Current configuration version: V1.4
# Date：2023-12-1
####################################################################################
# This product (Neptune 4/4pro/4plus/4max) adopts Klipper firmware 
# and does not support users to update the official klipper/fluidd
# /moonraker by themselves, otherwise the machine will not work properly.
# If you want to DIY and are an expert or interested in this field, 
# we recommend that you prepare your own tools for burning images so 
# that you can restore them if problems arise. Please contact after-sales 
# support team for tutorials on burning images. Thank you for your cooperation!
####################################################################################
# This file contains common pin mappings for ZNP-K1-V1.0 
# boards. To use this config, the firmware should be compiled for the
# STM32F402. When running "make menuconfig", enable "extra low-level
# configuration setup", select the 32KiB bootloader, and serial (on
# USART1 PA10/PA9) communication.

# The "make flash" command does not work on the ZN-K1-V1.0. Instead,
# after running "make", copy the generated "out/klipper.bin" file to a
# file named "elegoo_k1.bin" on an SD card and then restart the ZNP-K1-V1.0
# with that SD card.

# See docs/Config_Reference.md for a description of parameters.
####################################################################################


[include plr.cfg]

[include neptune4pro_autotune.cfg]

[include btt-eddy-zoffset.cfg]

#[include adxlmcu.cfg]

[auto_speed]
margin: 2.5 ; How far away from your axes to perform movements
accel_min: 1000.0 ; Minimum acceleration test may try
accel_max: 30000.0 ; Maximum acceleration test may try

velocity_min: 50.0 ; Minimum velocity test may try
velocity_max: 700.0 ; Maximum velocity test may try

[mcu]
# The hardware use USART1 PA10/PA9 connect to RK3328
serial: /dev/ttyS0
restart_method: command

[stepper_x]
step_pin:PC14
dir_pin:PC13
enable_pin:!PC15
microsteps: 128
rotation_distance: 40
full_steps_per_rotation:200  #set to 400 for 0.9 degree stepper
endstop_pin:PC0
position_min: -8.5  
position_endstop:-8
position_max: 238.7
homing_speed:50
homing_retract_dist:5
homing_positive_dir:false

[stepper_y]
step_pin:PB4
dir_pin:PB3
enable_pin:!PB5
microsteps: 128
rotation_distance: 40
full_steps_per_rotation:200  #set to 400 for 0.9 degree stepper
endstop_pin:PB8
position_min: -0.5
position_endstop: 0 
position_max:238.7
homing_speed:50
homing_retract_dist:5
homing_positive_dir:false


[stepper_z]
step_pin:PC10
dir_pin:!PA15
enable_pin: !PC11
microsteps: 128 #16
rotation_distance: 8
full_steps_per_rotation: 200
endstop_pin:probe:z_virtual_endstop ## PB12 for Z-max; endstop have'!' is NO

##  Z-position of nozzle (in mm) to z-endstop trigger point relative to print surface (Z0)
##  (+) value = endstop above Z0, (-) value = endstop below
##	Increasing position_endstop brings nozzle closer to the bed
##  After you run Z_ENDSTOP_CALIBRATE, position_endstop will be stored at the very end of your config
#position_endstop:-5
position_max: 268
position_min: -12
homing_speed: 8
homing_retract_dist: 5
second_homing_speed: 3

[extruder]
step_pin:PA5
dir_pin:!PA6
enable_pin:!PA4
microsteps: 64 #16
rotation_distance: 28.994 #29.0  #31.4	#Bondtech 5mm Drive Gears
gear_ratio: 52:10
full_steps_per_rotation: 200	#200 for 1.8 degree, 400 for 0.9 degree
nozzle_diameter: 0.400
filament_diameter: 1.750
min_temp: 0
max_temp: 310
heater_pin: PA7
sensor_type:NTC 100K MGB18-104F39050L32
sensor_pin: PA1
max_power: 1
#control :pid
#pid_kp : 26.213
#pid_ki : 1.304
#pid_kd : 131.721
pressure_advance: 0.022
pressure_advance_smooth_time: 0.04
instantaneous_corner_velocity: 2.5
max_extrude_only_distance: 300
max_extrude_only_velocity:60
max_extrude_only_accel:5000
max_extrude_cross_section: 9999999
min_extrude_temp:100

[verify_heater extruder]
max_error: 120
check_gain_time:30
hysteresis: 10
heating_gain: 2

[heater_bed]
heater_pin:PB10
sensor_type: NTC 100K MGB18-104F39050L32
sensor_pin: PA0
max_power: 1.0
#control : pid
#pid_kp : 75.397
#pid_ki : 0.823
#pid_kd : 1727.531
pwm_cycle_time: 0.016
min_temp: 0
max_temp: 120


[verify_heater heater_bed]
max_error: 120
check_gain_time:30
hysteresis: 10
heating_gain: 2



[respond]
default_type: echo
default_prefix: echo:

[virtual_sdcard]
path: ~/gcode_files
on_error_gcode:  
    # test OK
    G91
    G1 Z25 F900
    G90
    TURN_OFF_HEATERS
    M106 S100
    M84
    M300 P10000 S1
    G4 P300
    M300
    M300
    M300
    M300
    M300
    M300
    M300
    M300
    M300
    M300
    M300

########################################
# PRINT_START/CANCEL_PRINT/PAUSE/RESUME/filament_switch_sensor
########################################

[print_stats]

[gcode_move]

[gcode_macro PRINT_START]         
gcode:
    RESPOND PREFIX=print_start MSG="Printing..."
    SKEW_PROFILE LOAD=CaliFlower
    SAVE_VARIABLE VARIABLE=was_interrupted VALUE=True
	  G92 E0   
	  G90    
    CLEAR_PAUSE
    RESPOND PREFIX=print_start MSG="Printing...."                 
    
[gcode_macro PRINT_END]
gcode:
    SET_SKEW CLEAR=1
    SAVE_VARIABLE VARIABLE=was_interrupted VALUE=False
    RUN_SHELL_COMMAND CMD=clear_plr
    clear_last_file
    {% set RUN_VELOCITY = printer.configfile.settings['printer'].max_velocity|float %}
    {% set RUN_ACCEL    = printer.configfile.settings['printer'].max_accel|float %}
    {% set RUN_CRUISE   = printer.configfile.settings['printer'].minimum_cruise_ratio|float %}
    SET_VELOCITY_LIMIT VELOCITY={RUN_VELOCITY} ACCEL={RUN_ACCEL} MINIMUM_CRUISE_RATIO={RUN_CRUISE}
    M220 S100
    M221 S100
    {% set z = params.Z|default(100)|int %} 
    {% if (printer.gcode_move.position.z+5) < z %}
      G90 
      G1 Z{z+5} F6000 
    {% endif %}
    TURN_OFF_HEATERS
    M107
    M84


[gcode_macro CANCEL_PRINT]
rename_existing: BASE_CANCEL_PRINT
gcode:
    SAVE_VARIABLE VARIABLE=was_interrupted VALUE=False
    RUN_SHELL_COMMAND CMD=clear_plr
    clear_last_file
    {% set RUN_VELOCITY = printer.configfile.settings['printer'].max_velocity|float %}
    {% set RUN_ACCEL    = printer.configfile.settings['printer'].max_accel|float %}
    {% set RUN_CRUISE   = printer.configfile.settings['printer'].minimum_cruise_ratio|float %}
    SET_VELOCITY_LIMIT VELOCITY={RUN_VELOCITY} ACCEL={RUN_ACCEL} MINIMUM_CRUISE_RATIO={RUN_CRUISE}
    {% set z = params.Z|default(100)|int %}  
    {% set x_park = params.X|default(printer.toolhead.axis_minimum.x+5)|int %} 
    {% set y_park = params.Y|default(printer.toolhead.axis_maximum.y-5)|int %} 
    SET_IDLE_TIMEOUT TIMEOUT={printer.configfile.settings.idle_timeout.timeout} 
    SDCARD_RESET_FILE
    M220 S100
    M221 S100
    M400
    G91
    M83
    G1 E-10.0 F1200
    TURN_OFF_HEATERS
    M107
    {% if (printer.gcode_move.position.z+5) < z %}
    G90
    G0 X{x_park} Y{y_park} Z{z+5} F6000
    {% endif %}
    {%if (printer.gcode_move.position.z+5) >= z %}
    {%if (printer.gcode_move.position.z+5) < printer.toolhead.axis_maximum.z %}
    G91
    G1 Z5 F300
    G90
    G0 X{x_park} Y{y_park} F6000
    {% else %}
    G90
    G0 X{x_park} Y{y_park} Z{printer.toolhead.axis_maximum.z} F6000
    {% endif %}
    {% endif %}
    M84

[pause_resume]
recover_velocity: 50.0
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

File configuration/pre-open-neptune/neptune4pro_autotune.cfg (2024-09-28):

########################################
##  AutoTune motor profile for the Netpune 4 Pro base configuration motors
##          08/30/2024   v 1.0
##          use at your own risk, these have been tested to function, but no support or cert is provided
##          for Autotune documentation and use of the motor config, please see
##              https://github.com/andrewmcgr/klipper_tmc_autotune
##
##          The base motors for the Neptune 4 Pro are not included in the motor_database.cfg
##          this is the custom motor definition as documented User-defined motor section of the Readme.md
##
##          Recomended implementation and pre-requisits
##              Because AutoTune required python3, you will need to be on OpenNept4une
##                      https://github.com/OpenNeptune3D/OpenNept4une
##              Include this place this cfg in your klipper_tmc_autotune directory
##              add a line to your printer.cfg to include this file
##              
##              The BJ42D22-53V04 is the 1.2A X & Y stepper motor on the pro
##              The BJ42D15-26V77 is the 0.8A X & Y stepper motor on the pro
##              The BJ36D12-04V05 is the Extruder stepper motor on the pro
##              
##              follow the instructions on the how to enable the motor in your tmc_autotune sections of the printer.cfg


[motor_constants bj42d22-53v04]             ; 1.2A version of the stepper motor
resistance: 2.1
inductance: 0.0046
holding_torque: 0.4
max_current: 1.20
steps_per_revolution: 200


############                                ; 0.8A version of the stepper motor
[motor_constants bj42d15-26v77]
resistance: 6
inductance: 0.0088
holding_torque: 0.28
max_current: 0.8
steps_per_revolution: 200

###############                             ;   0.8A version of the z axis stepper motor
[motor_constants bj42d15-26v78]
resistance: 6.5
inductance: 0.00826
holding_torque: 0.28                       
max_current:    0.8
steps_per_revolution: 200

##############                              ; Extruder motor - enable if you are doing extruder auto-tune
[motor_constants bj36d12-04v05]
resistance: 2.0
inductance: 0.0014
holding_torque: 0.09
max_current: 1.0
steps_per_revolution: 200

[autotune_tmc stepper_x]
motor: bj42d22-53v04
tuning_goal: silent #options: auto, silent, performance, and autoswitch(experimental!)

[autotune_tmc stepper_y]
motor: bj42d22-53v04
tuning_goal: silent #options: auto, silent, performance, and autoswitch(experimental!)

[autotune_tmc stepper_z]
motor: bj42d15-26v78
tuning_goal: silent #options: auto, silent, performance, and autoswitch(experimental!)

# [autotune_tmc extruder]
# motor: bj36d12-04v05
# tuning_goal: silent #options: auto, silent, performance, and autoswitch(experimental!)

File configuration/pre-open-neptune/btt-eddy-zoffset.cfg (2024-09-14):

# The MCU section only applies to the Eddy USB. For Eddy Coil you will use the MCU name of the toolboard that you connected the Eddy Coil to.
[mcu eddy]
serial: /dev/serial/by-id/usb-Klipper_rp2040_45474E621B0483CA-if00
restart_method: command

[temperature_sensor btt_eddy_mcu]
sensor_type: temperature_mcu # Sets the type of sensor for Klipper to read
sensor_mcu: eddy # Sets the MCU of the eddy probe tempereature sensor
min_temp: 10 # Sets the minimum tempereature for eddys tempereature sensor to operate
max_temp: 100 # Sets the maximum tempereature for eddys tempereature sensor to operate

[probe_eddy_current btt_eddy]
sensor_type: ldc1612
z_offset: 2.5
#i2c_address:
i2c_mcu: eddy  # This value is good for the Eddy USB but would need to be adjusted for the Eddy Coil according to the MCU you have used.
i2c_bus: i2c0f # This value is good for the Eddy USB but would need to be adjusted for the Eddy Coil according to the I2C bus you have used.
# Measure the offsets below using the method described here: https://www.klipper3d.org/Probe_Calibrate.html#calibrating-probe-x-and-y-offsets
# For a standard Voron stealthburner X carriage mount there should be no need to change the defaults below.
x_offset: -36.16
y_offset: 31.66

# This section is only relevant for Eddy USB. Comment it out for Eddy Coil.
[temperature_probe btt_eddy]
sensor_type: Generic 3950
sensor_pin: eddy:gpio26
horizontal_move_z: 2

[bed_mesh]
horizontal_move_z: 2
speed: 400
# For the mesh dimensions below, the coordinates need to be reachable by the center of the probe. To calculate coordinates that will work, use the formula below:
# mesh x min = position_min_x + greater_of (15mm or x_offset) <--- in this term, only consider the x offset if it is positive, ignore if negative.
# mesh y min = position_min_y + greater_of (15mm or y_offset) <--- in this term, only consider the y offset if it is positive, ignore if negative.
# mesh x max = position_max_x - greater_of (15mm or |x_offset|) <--- in this term, only consider the x offset if it is negative, ignore if positive.
# mesh y max = position_max_y - greater_of (15mm or |y_offset|) <--- in this term, only consider the y offset if it is negative, ignore if positive.
# Example: Consider that you have a 300 x 300 bed with the max x and y positions being 300 and the min being 0. Your probe offsets are -20 for X and 10 for Y
# For mesh x min we ignore the x offset term because it is negative. Therefore mesh x min = 15
# For mesh y min we do not ignore the y offset term because it is positive but it is less than 15 so we use 15. Therefore mesh y min = 15
# For mesh x max we do not ignore the x offset term because it is negative. It is also greater than 15. Therefore mesh x max = 280
# For mesh y max we ignore the y offset term because it is positive but it is less than 15 so we use 15. Therefore mesh y max = 285
# The final result would be mesh_min: 15, 15 mesh_max: 280, 285
mesh_min: 15, 31.66 # modify these according to the above guide. If the probe cannot reach then you will get a klipper error when trying to scan a bed mesh.
mesh_max: 198.84, 220.00 # 197.94, 203.44 # modify these according to the above guide. If the probe cannot reach then you will get a klipper error when trying to scan a bed mesh.
probe_count: 21, 21 
algorithm: bicubic
#scan_overshoot: 8  #uncomment this section if you still have room left over on the X axis for some scan overshoot to product smoother movements and more accurate scanning. Uncommenting this should be fine if you are using a standard voron mount.

# Uncomment this if you are using Eddy as the probe AND the homing endstop
[safe_z_home]
home_xy_position: 117.5, 117.5 # Choose an X,Y position that is in the center of your bed. For a 300x300 machine that will be 150, 150. Use the same principle to calculate your bed center.
z_hop: 10
z_hop_speed: 25
speed: 200

###############################Macros and related################################
#This secton contains macros and related config sections. Some should be used, others are optional. Read the comment above each one to find out whether or not to uncomment it for your installation.


# Uncomment this if you are using Eddy as the probe AND the homing endstop AND would like to use the beta z-offset control
[save_variables]
filename: ~/printer_data/config/variables.cfg



# Uncomment this if you are using Eddy as the probe AND the homing endstop
[force_move]
enable_force_move: True # Allows a user to move the z axis down if they have no other means of homing Z and need to calibrate the Eddy.



# Uncomment this if you are using Eddy as the probe AND the homing endstop AND would like to use the beta z-offset control
[delayed_gcode RESTORE_PROBE_OFFSET]
initial_duration: 1.
gcode:
  {% set svv = printer.save_variables.variables %}
  {% if not printer["gcode_macro SET_GCODE_OFFSET"].restored %}
    SET_GCODE_VARIABLE MACRO=SET_GCODE_OFFSET VARIABLE=runtime_offset VALUE={ svv.nvm_offset|default(0) }
    SET_GCODE_VARIABLE MACRO=SET_GCODE_OFFSET VARIABLE=restored VALUE=True
  {% endif %}



# Uncomment this if you are using Eddy as the probe AND the homing endstop
# Take note of the lines that should only be used if you have a KNOMI installed.
[gcode_macro G28]
rename_existing: G28.1
gcode:
  #SET_GCODE_VARIABLE MACRO=_KNOMI_STATUS VARIABLE=homing VALUE=True # Uncomment this if using a KNOMI and then remove the G28 macro from the KNOMI.cfg
  G28.1 {rawparams}
  {% if not rawparams or (rawparams and 'Z' in rawparams) %}
    PROBE
    SET_Z_FROM_PROBE
  {% endif %}
  #SET_GCODE_VARIABLE MACRO=_KNOMI_STATUS VARIABLE=homing VALUE=False # Uncomment this if using a KNOMI and then remove the G28 macro from the KNOMI.cfg



# Uncomment this if you are using Eddy as the probe AND the homing endstop
[gcode_macro SET_Z_FROM_PROBE]
gcode:
    {% set cf = printer.configfile.settings %}
    SET_GCODE_OFFSET_ORIG Z={printer.probe.last_z_result - cf['probe_eddy_current btt_eddy'].z_offset + printer["gcode_macro SET_GCODE_OFFSET"].runtime_offset}
    G90
    G1 Z{cf.safe_z_home.z_hop}


# Uncomment this if you are using Eddy as the probe AND the homing endstop AND would like to use the beta z-offset control
[gcode_macro Z_OFFSET_APPLY_PROBE]
rename_existing: Z_OFFSET_APPLY_PROBE_ORIG
gcode:
  SAVE_VARIABLE VARIABLE=nvm_offset VALUE={ printer["gcode_macro SET_GCODE_OFFSET"].runtime_offset }



# Uncomment the lines in this macro if you are using Eddy as the probe AND the homing endstop AND would like to use the beta z-offset control
[gcode_macro SET_GCODE_OFFSET]
rename_existing: SET_GCODE_OFFSET_ORIG
variable_restored: False  # Mark whether the var has been restored from NVM
variable_runtime_offset: 0
gcode:
  {% if params.Z_ADJUST %}
    SET_GCODE_VARIABLE MACRO=SET_GCODE_OFFSET VARIABLE=runtime_offset VALUE={ printer["gcode_macro SET_GCODE_OFFSET"].runtime_offset + params.Z_ADJUST|float }
  {% endif %}
  {% if params.Z %} 
    {% set paramList = rawparams.split() %}
    {% for i in range(paramList|length) %}
      {% if paramList[i]=="Z=0" %}
        {% set temp=paramList.pop(i) %}
        {% set temp="Z_ADJUST=" + (-printer["gcode_macro SET_GCODE_OFFSET"].runtime_offset)|string %}
        {% if paramList.append(temp) %}{% endif %}
      {% endif %}
    {% endfor %}
    {% set rawparams=paramList|join(' ') %}
    SET_GCODE_VARIABLE MACRO=SET_GCODE_OFFSET VARIABLE=runtime_offset VALUE=0
  {% endif %}
  SET_GCODE_OFFSET_ORIG { rawparams }



# This macro automates a lot of the frequency mapping process and simplifies the steps significantly.
[gcode_macro PROBE_EDDY_CURRENT_CALIBRATE_AUTO]
gcode:
  BED_MESH_CLEAR
  G28 X Y
  G90 # Abs positioning
  G1 X{ printer.toolhead.axis_maximum.x/2 } Y{ printer.toolhead.axis_maximum.y/2 } F6000
  {% if 'z' not in printer.toolhead.homed_axes %}
    SET_KINEMATIC_POSITION Z={ printer.toolhead.axis_maximum.z-1 } # Allows the user to work it down until it touches.
  {% endif %}
  PROBE_EDDY_CURRENT_CALIBRATE {rawparams}



#This macro is optional but useful if you want to run a rapid scan before each print. Simply uncomment it and add BED_MESH_SCAN to your print start code.
#[gcode_macro BED_MESH_CALIBRATE]
#rename_existing: BTT_BED_MESH_CALIBRATE
#gcode:
#  SET_GCODE_VARIABLE MACRO=_KNOMI_STATUS VARIABLE=probing VALUE=True #Only uncomment this line if using a KNOMI and then remove the BED_MESH_CALIBRATE macro from KNOMI.cfg
#  BTT_BED_MESH_CALIBRATE METHOD=rapid_scan
#  SET_GCODE_VARIABLE MACRO=_KNOMI_STATUS VARIABLE=probing VALUE=False #Only uncomment this line if using a KNOMI and then remove the BED_MESH_CALIBRATE macro from KNOMI.cfg


#################################################################################
## My probe macros

[gcode_macro GET_BED_MESH]
gcode:
  BED_MESH_CLEAR
  G28
  BED_MESH_CALIBRATE METHOD=rapid_scan PROFILE=6
  BED_MESH_PROFILE LOAD="6"

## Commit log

2024-07-17 backup 2024-06-30
    [KAMP_Settings.cfg, adxlmcu.cfg, fluidd.cfg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]
2024-07-21 save work
    [compare.cfg, printer.cfg]
2024-07-22 update to my personal printer.cfg
    [printer.cfg]
2024-07-22 updates to my personal configs
    [KAMP_Settings.cfg, compare.cfg, moonraker-kamp-update.cfg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]
2024-08-31 Create Klipper TMC Autotune.md
2024-08-31 Update Klipper TMC Autotune.md
2024-09-04 Update printer.cfg 2024-09-03
    [printer.cfg]
2024-10-16 Updating my repo
    [adxlmcu.cfg, btt-eddy-zoffset.cfg, moonraker-obico-update.cfg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]
2024-11-15 z-endstop stl files
    [z-offset endstop-arm spacer.stl, z-offset endstop-arm.stl, z-offset endstop-base with keepers.stl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]
2024-11-15 Rename stl/z-offset endstop-arm spacer.stl to stl/z-endstop/z-offset endstop-arm spacer.stl
    [z-offset endstop-arm spacer.stl]
2024-11-15 Rename stl/z-offset endstop-arm.stl to stl/z-endstop/z-offset endstop-arm.stl
    [z-offset endstop-arm.stl]
2024-11-15 Rename stl/z-offset endstop-base with keepers.stl to stl/z-endstop/z-offset endstop-base with keepers.stl
    [z-offset endstop-base with keepers.stl]
2024-11-15 Rename stl/z-offset endstop-baseplate.stl to stl/z-endstop/z-offset endstop-baseplate.stl
    [z-offset endstop-baseplate.stl]
2024-11-15 Rename stl/z-offset endstop-cover.stl to stl/z-endstop/z-offset endstop-cover.stl
    [z-offset endstop-cover.stl]
2024-11-18 updated with fixes
    [z-offset endstop-cover.stl]
